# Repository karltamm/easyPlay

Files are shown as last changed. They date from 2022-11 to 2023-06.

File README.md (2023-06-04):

# EasyPlay

The aim of this project was to create a gadget that facilitates watching recorded lectures that are in a form of HTML5 video.

As a result of this, a custom-built hardware was designed and manufactured that communicates with a browser extension (_currently only on Firefox_) to control playback of HTML5 video and to
manage video bookmarks using graphical user interface (GUI).

## Demo Clips

- [Adding Bookmark](https://www.youtube.com/watch?v=zyzYwxNeeDU&list=PLD5j9DIB91if8dvnZOE8TOlPMy7ZPZOXh&index=4)
- [Bookmark List](https://www.youtube.com/watch?v=o9xNbJMG1ok&list=PLD5j9DIB91if8dvnZOE8TOlPMy7ZPZOXh&index=4)
- [Playing Bookmark](https://www.youtube.com/watch?v=D4asH7l5GT0&list=PLD5j9DIB91if8dvnZOE8TOlPMy7ZPZOXh&index=5)
- [Deleting Bookmark](https://www.youtube.com/watch?v=MK7uui3cbB4&list=PLD5j9DIB91if8dvnZOE8TOlPMy7ZPZOXh&index=6)
- [Choosing Playback Speed](https://www.youtube.com/watch?v=vUmaLGZ5vVY&list=PLD5j9DIB91if8dvnZOE8TOlPMy7ZPZOXh&index=1)
- [Rewinding & Fast-Forwarding](https://www.youtube.com/watch?v=-IeWby0tvKw&list=PLD5j9DIB91if8dvnZOE8TOlPMy7ZPZOXh&index=2)

## Hardware

- STM32F042C6T6 microcontroller (ARM Cortex-M0)
- Illuminated mechanical switches (Cherry MX) and knob (incremental rotary encoder)
- USB Type-C connector for communication and power delivery
- Custom designed [printed circuit board](https://raw.githubusercontent.com/karltamm/EasyPlay/main/hardware/Outputs/PCB%203D%20Print/PCB%203D%20model%20top.png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) (PCB) and enclosure ([exploded rendering](https://github.com/karltamm/EasyPlay/blob/main/enclosure/images/device-exploded-view.png) & [finished](https://github.com/karltamm/EasyPlay/blob/main/enclosure/images/assembled-device.png))

## Device Firmware

- Written in C
- Software based debounce for buttons and knob
- Simple task manager

## Device Driver

- Written in Java
- Uses [jSerialComm](https://fazecast.github.io/jSerialComm/) to communicate with the firmware
- Communicates with the browser extension using [native messaging protocol](https://developer.mozilla.org/en-US/docs/Mozilla/Add-ons/WebExtensions/Native_messaging)

## Browser extension

- Written in TypeScript
- Controls HTML5 video playback
- Allows to use video bookmarks using GUI (built with React)

## Driver Installer

- Written in C++
- Uses [Qt framework](https://www.qt.io/product/framework)
- Copies driver to chosen location
- Sets up [app manifest](https://developer.mozilla.org/en-US/docs/Mozilla/Add-ons/WebExtensions/Native_messaging#app_manifest) to use browser native messaging for communication between the driver and browser extension

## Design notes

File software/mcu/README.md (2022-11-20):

# Abbreviations used in source code

- btn - button
- CCW - counterclockwise
- comm - communication
- conn - connection
- cur - current
- CW - clockwise
- g\_ - global (variable naming)
- init - initialize
- len - length
- ms - millisecond
- msg - message
- PC - personal computer
- RX - receive
- TX - transmit
- UI - user interface
- sw - switch

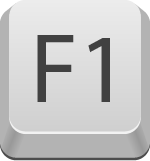
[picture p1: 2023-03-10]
software/extension/src/assets/images/150w/keycap-f1.png

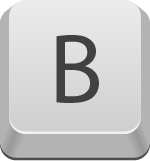
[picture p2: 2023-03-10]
software/extension/src/assets/images/150w/keycap-b.png

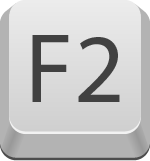
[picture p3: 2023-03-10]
software/extension/src/assets/images/150w/keycap-f2.png

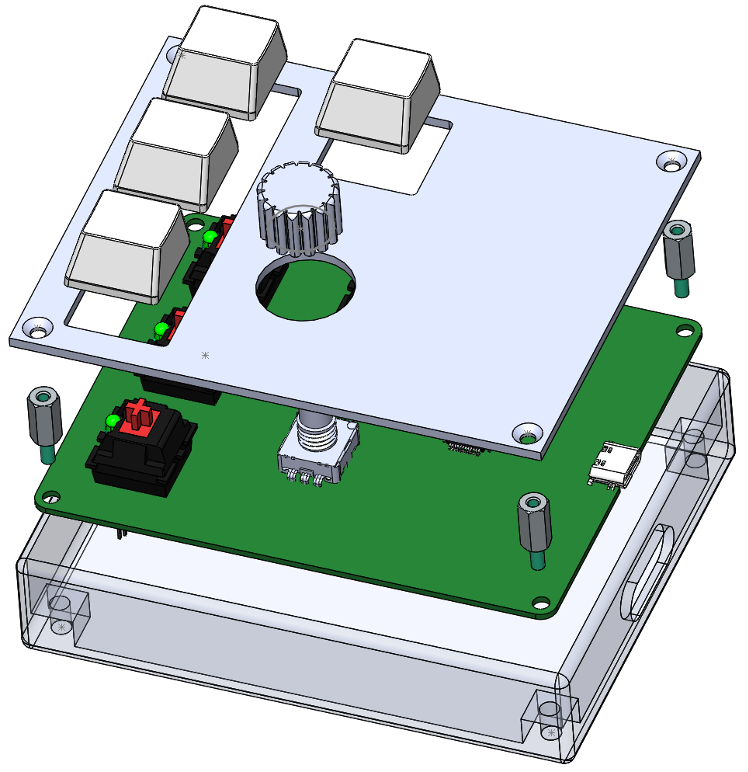
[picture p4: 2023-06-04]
enclosure/images/device-exploded-view.png

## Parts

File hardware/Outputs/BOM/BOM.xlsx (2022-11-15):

Library Reference | Manufacturer | Manufacturer ID | Supplier | Supplier ID | Quantity | Comment | Designator
5x1 Pin Header | AMPHENOL | 68000-105HLF | Farnell | 2751380 | 1 | ST-LINK | CON1-MCU
Capacitor | MULTICOMP PRO | MC0603B104J500CT | Farnell | 2320803 | 13 | 0.1uF, 50V, 0603 | C1-CTRL, C1-MCU, C2-CTRL, C2-MCU, C2-PWR, C3-CTRL, C3-MCU, C4-MCU, C4-PWR, C5-MCU, C6-CTRL, C7-CTRL, C7-MCU
Capacitor | MULTICOMP PRO | MC0603N200J500CT | Farnell | 2627461 | 2 | 20pF, 50V, 0603 | C6-MCU, C8-MCU
Capacitor | MURATA | GRM21BR6YA106KE43L | Farnell | 2611943 | 2 | 10uF, 35V, 0805 | C1-PWR, C3-PWR
Capacitor | YAGEO | CC0603KRX7R8BB103 | Farnell | 3019561 | 2 | 10nF, 25V, 0603 | C4-CTRL, C5-CTRL
Cherry MX Switch | Cherry Americas LLC | MX1A-11NW | Digi-Key | CH160-ND | 4 | Cherry MX, 10mA, 12V | SW1-CTRL, SW2-CTRL, SW3-CTRL, SW5-CTRL
Crystal 4-pin | MULTICOMP PRO | MCSJK-7U-25.00-12-10-60-B-10 | Farnell | 2853968 | 1 | 25MHz, 12pF, 3.2x2.5mm | Y1-MCU
ESD Protection Device | NEXPERIA | IP4234CZ6,125 | Farnell | 1829276 | 1 | 100W, SOT457 | U1-USB
LDO Regulator | Microchip | MCP1700T-3302E/TT | Farnell | 1296592 | 1 | 3.3V, 250mA | U1-PWR
LED | BROADCOM | HLMP-1401 | Farnell | 1003198 | 1 | 2Vf, 10mA, yellow, TH, no footprint | D2-CTRL
LED | KINGBRIGHT | KP-1608CGCK | Farnell | 2290328 | 1 | 2.1Vf, 20mA, green, 0603 | D2-MCU
LED | KINGBRIGHT | KP-1608SYC | Farnell | 8529841 | 1 | 2Vf, 20mA, yellow, 0603 | D1-MCU
LED | MULTICOMP PRO | MP008246 | Farnell | 3796272 | 3 | 1.8Vf, 2mA, green, TH, no footprint | D1-CTRL, D3-CTRL, D4-CTRL
LED | VISHAY | VLMS1300-GS08 | Farnell | 2251484 | 1 | 2Vf, 20mA, red, 0603 | D2-PWR
Molex USB 2.0 Type-C Receptacle | MOLEX | 216990-0003 | Farnell | 3702962 | 1 | UFP | CON1-USB
Resistor | BOURNS | CR0603-FX-1001ELF | Farnell | 2008335 | 9 | 1k, 100mW, 0603 | R3-CTRL, R4-CTRL, R5-CTRL, R6-CTRL, R9-CTRL, R11-CTRL, R15-CTRL, R17-CTRL, R18-CTRL
Resistor | MULTICOMP PRO | MC0805S8F0000T5E | Farnell | 2309112 | 4 | 0R, 125mW, 0805 | R1-USB, R2-USB, R3-USB, R4-USB
Resistor | YAGEO | RC0603FR-075K1L | Farnell | 3495881 | 2 | 5.1k, 100mW, 0603 | R5-USB, R6-USB
Resistor | YAGEO | RC0603FR-0710KL | Farnell | 9238603 | 4 | 10k, 100mW, 0603 | R8-CTRL, R10-CTRL, R12-CTRL, R13-CTRL
Resistor | YAGEO | RC0603FR-07270RL | Farnell | 9238417 | 3 | 270R, 100mW, 0603 | R1-MCU, R1-PWR, R2-MCU
Resistor | YAGEO | RC0603FR-13100KL | Farnell | 2309107 | 5 | 100k, 100mW, 0603 | R1-CTRL, R2-CTRL, R7-CTRL, R14-CTRL, R16-CTRL
Rotary Encoder w/ Switch | Bourns | PEC11H-4015F-S0016 | Digi-Key | 118-PEC11H-4015F-S0016-ND | 1 | Rotary Encoder w/ Switch | SW4-CTRL
Schottky Rectifier (Diode) | NEXPERIA | PMEG3030EP,115 | Farnell | 1829195 | 1 | 30Vbr, 3A, 360mVf | D1-PWR
STM32F042C6T6 (MCU) | STMicroelectronics | STM32F042C6T6 | JLCPCB | C88447 | 1 | STM32F042C6T6 | U1-MCU

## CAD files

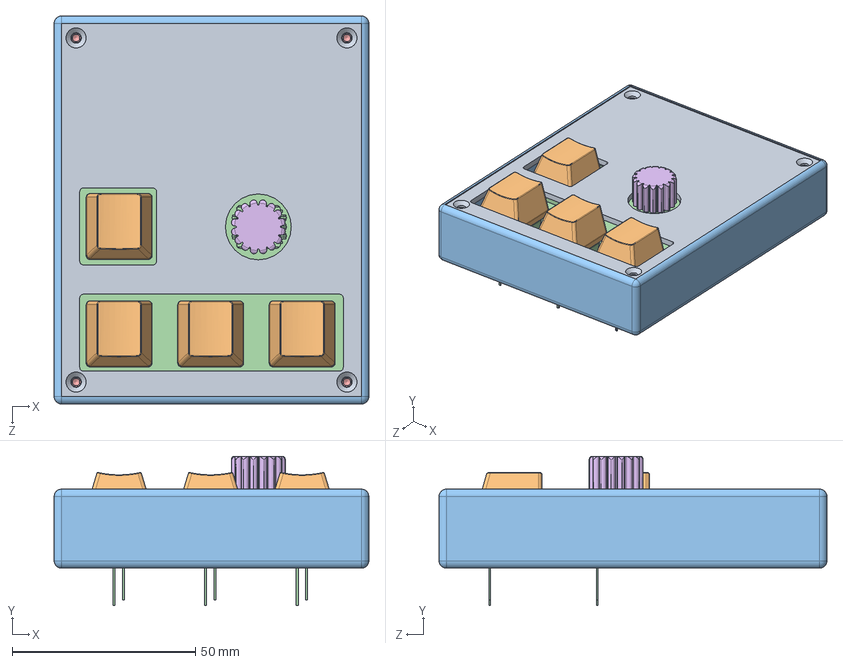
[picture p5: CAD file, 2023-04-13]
enclosure/DeviceAssembly.SLDASM
86.0 x 40.8 x 106.0 mm
PCB
Standoff x 4
Keycap x 4
Knob cap
Lid

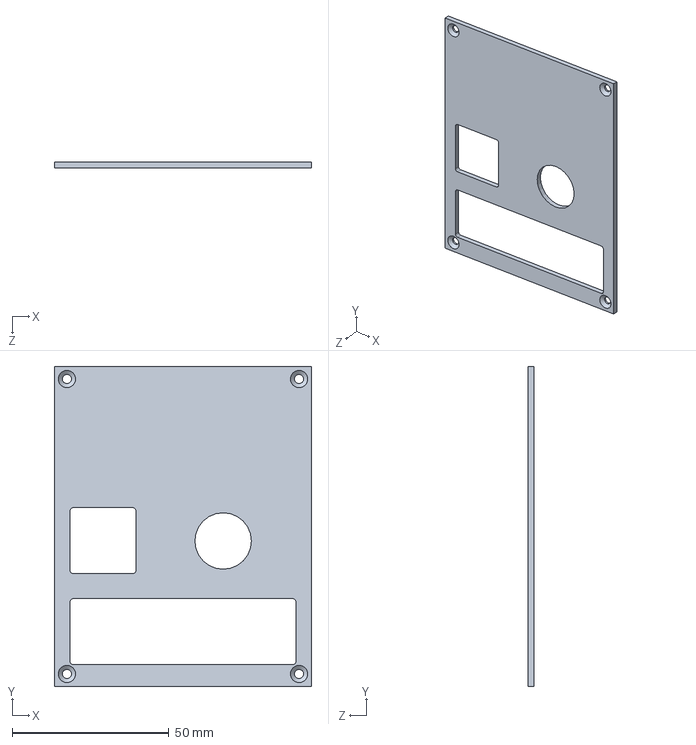
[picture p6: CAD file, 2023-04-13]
enclosure/Lid.SLDPRT
82.0 x 102.0 x 2.00 mm

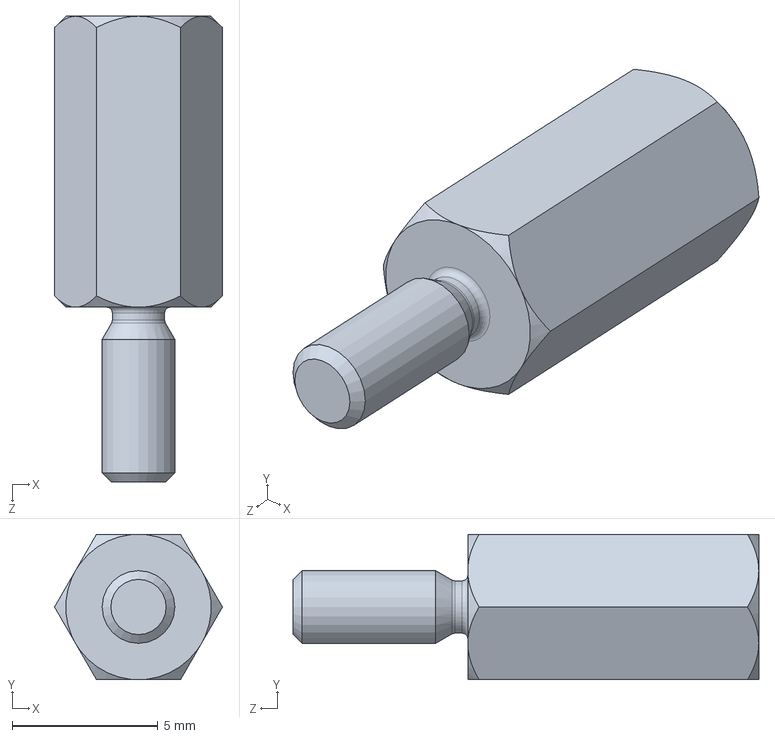
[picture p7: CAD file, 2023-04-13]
enclosure/products/Standoff.SLDPRT
5.77 x 5.00 x 16.0 mm

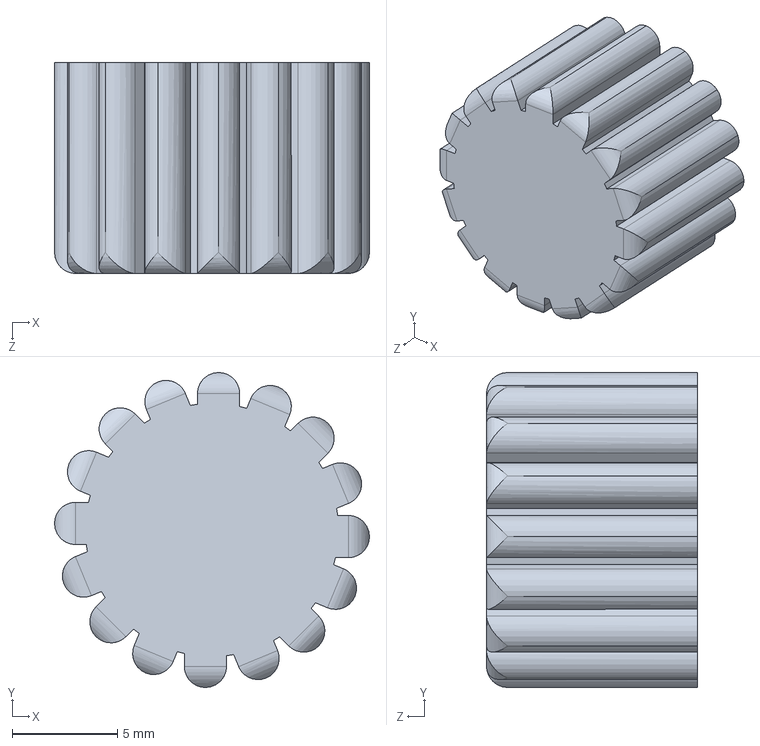
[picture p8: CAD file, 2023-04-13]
enclosure/Knob cap.SLDPRT
14.9 x 14.9 x 10.0 mm

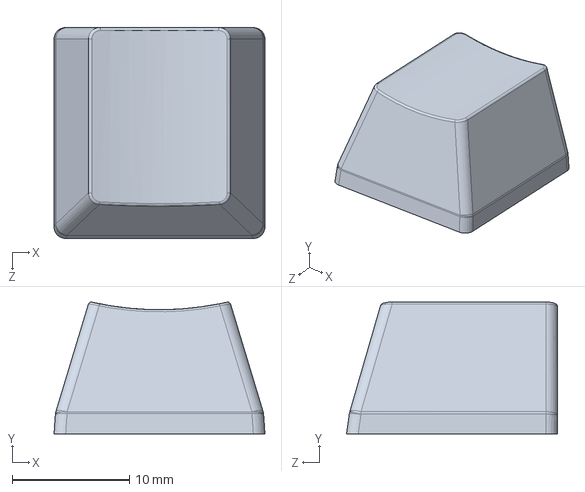
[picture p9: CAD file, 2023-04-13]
enclosure/products/Keycap.SLDPRT
18.0 x 11.3 x 18.0 mm

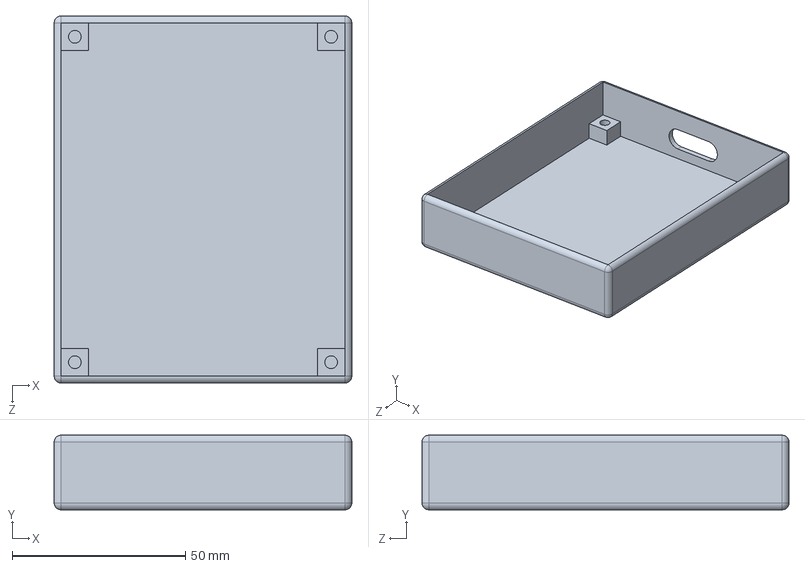
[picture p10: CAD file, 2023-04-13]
enclosure/Box.SLDPRT
86.0 x 21.6 x 106.0 mm

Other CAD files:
enclosure/stl/Box.STL
enclosure/stl/Knob cap.STL
enclosure/stl/Lid.STL

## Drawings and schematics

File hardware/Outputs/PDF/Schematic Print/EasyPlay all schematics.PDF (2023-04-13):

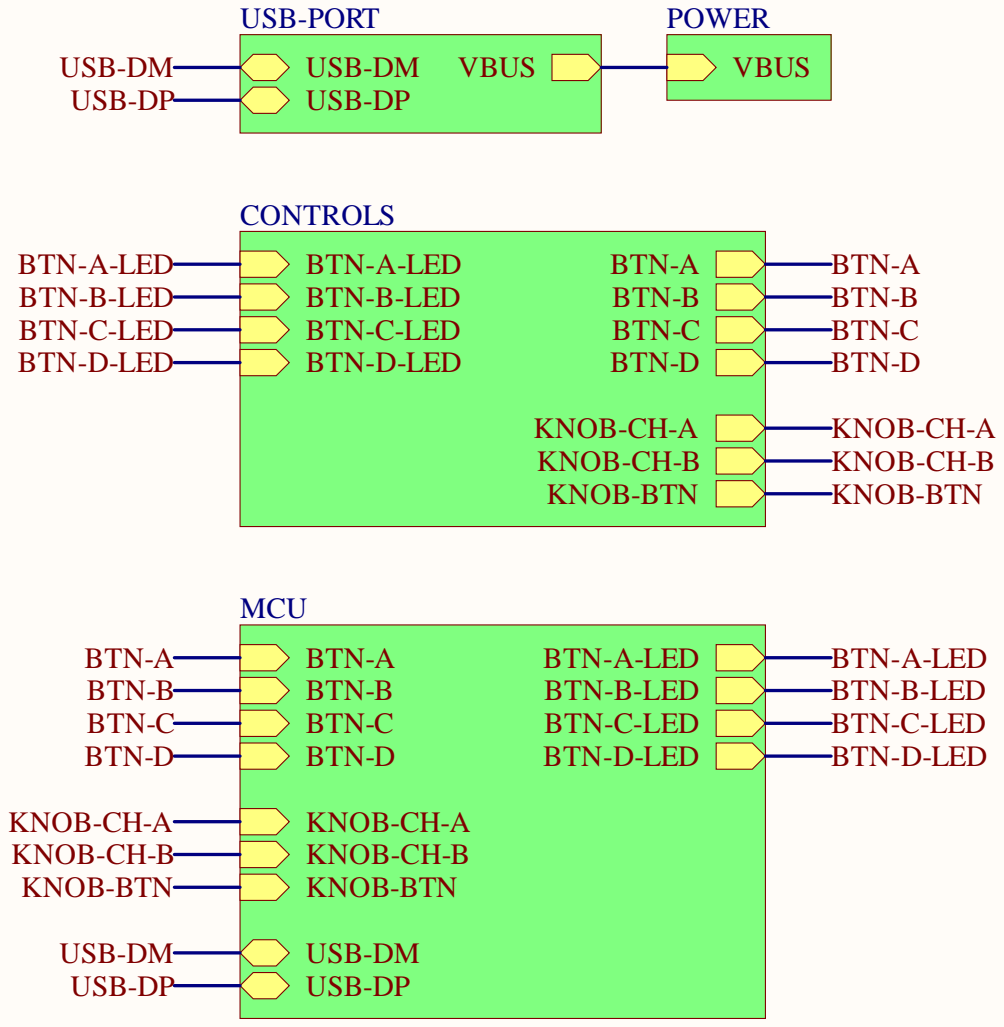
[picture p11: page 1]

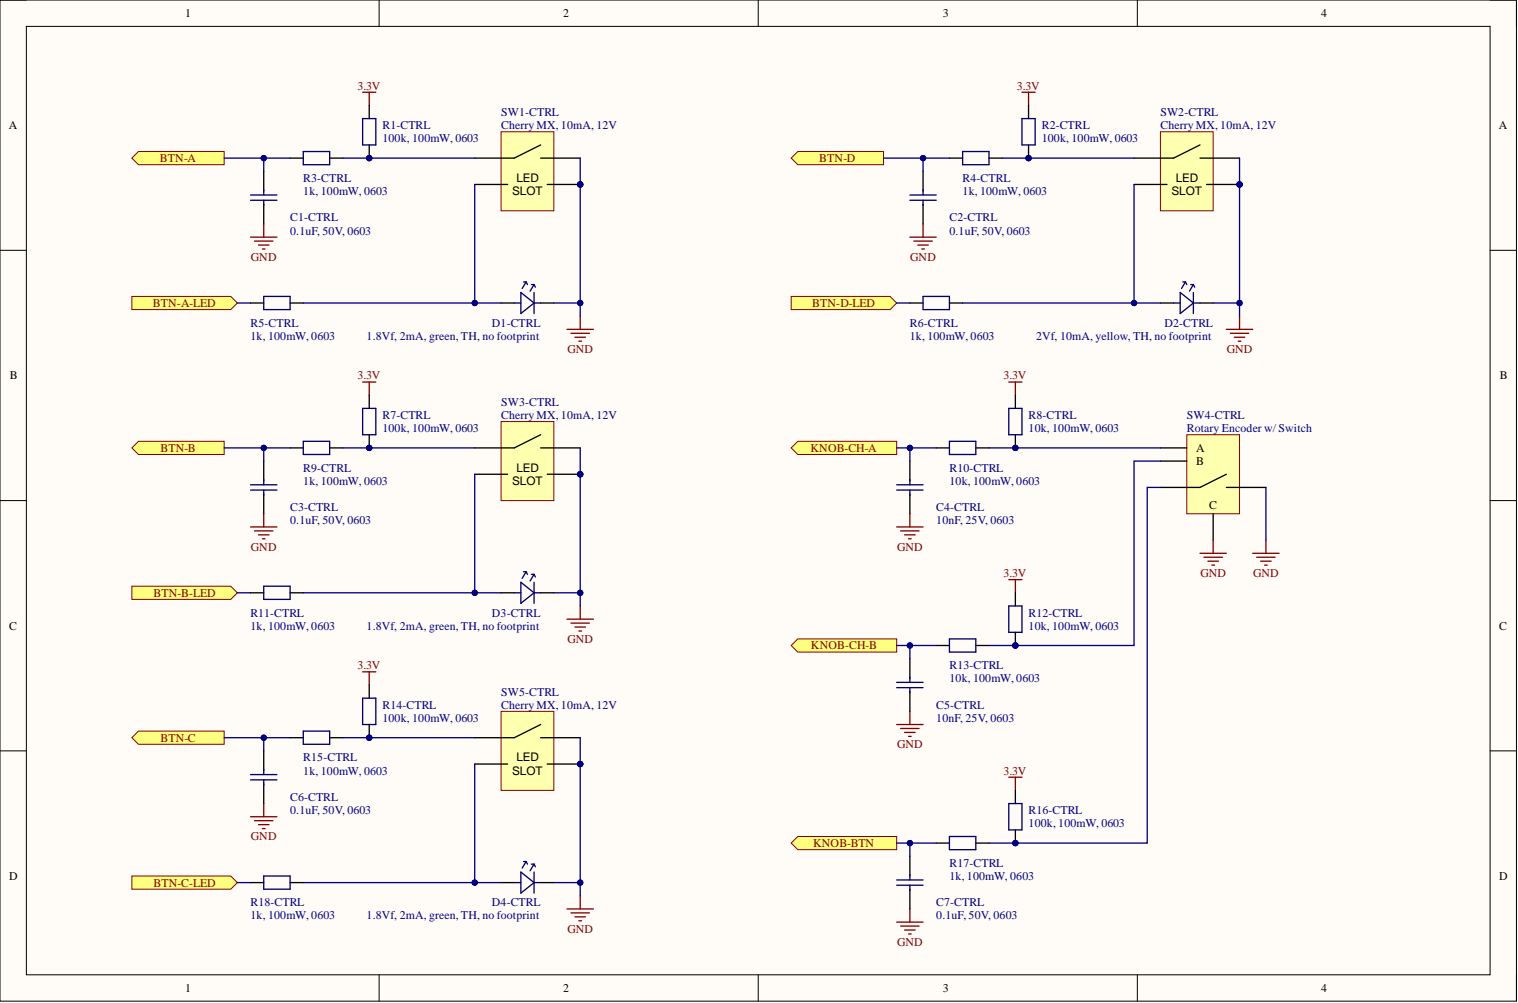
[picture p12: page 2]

1.8Vf, 2mA, green, TH, no footprint

2Vf, 10mA, yellow, TH, no footprint

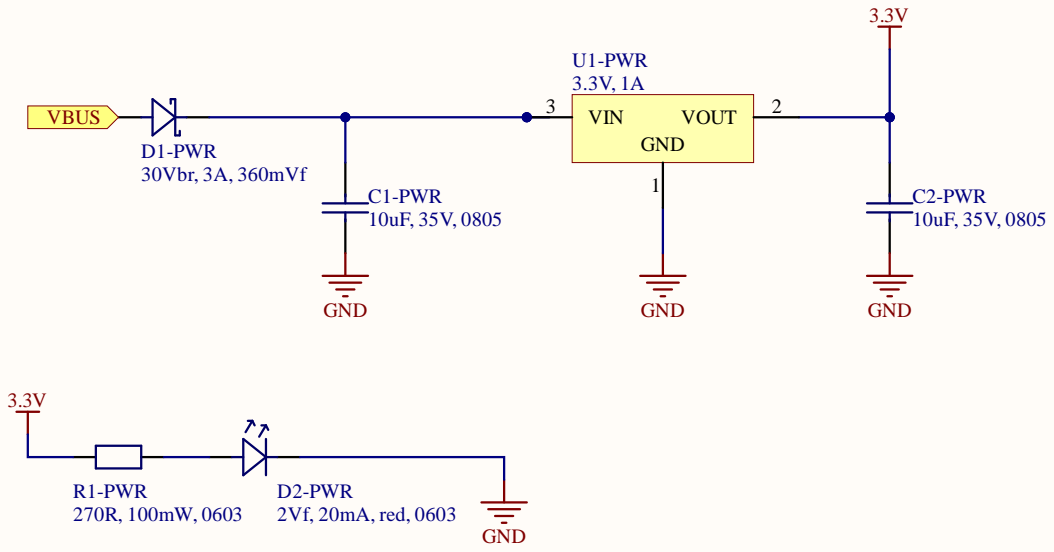
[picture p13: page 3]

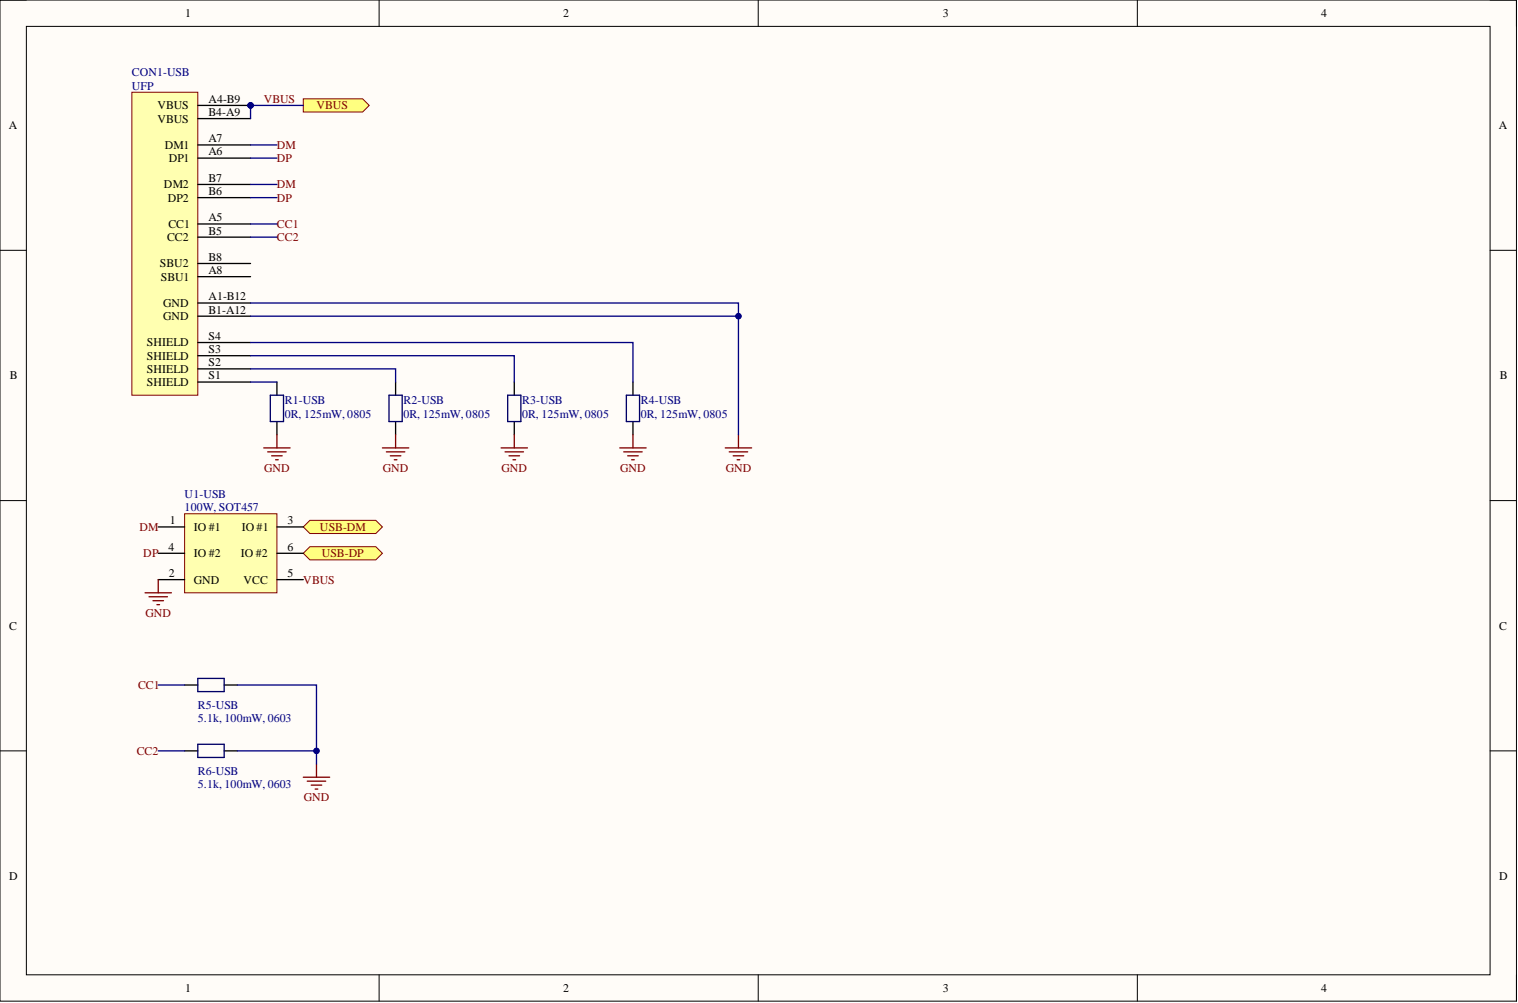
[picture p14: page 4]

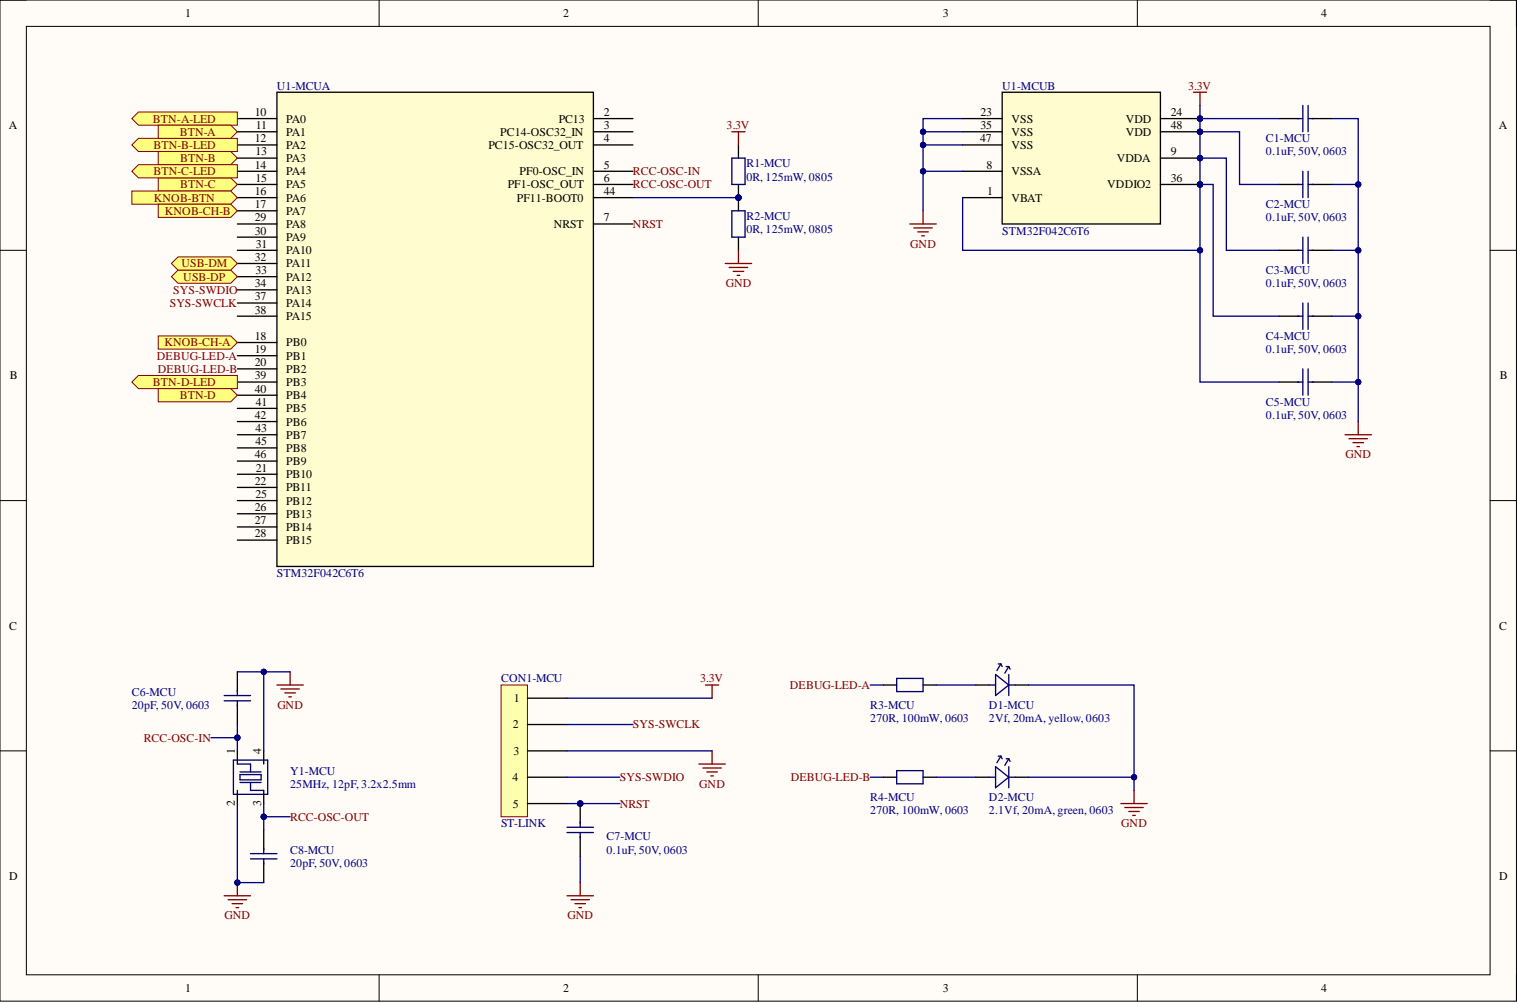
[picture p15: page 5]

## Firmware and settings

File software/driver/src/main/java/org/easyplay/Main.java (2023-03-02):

package org.easyplay;

import lombok.extern.slf4j.Slf4j;

import static org.easyplay.UsbCommunicator.USB_RX_QUEUE_MAX_SIZE;
import static org.easyplay.UsbCommunicator.USB_TX_QUEUE_MAX_SIZE;


@Slf4j
public class Main {
    public static void main(String[] args) {
        log.info("Booting up app");
        UsbQueue usbTxQueue = new UsbQueue(USB_TX_QUEUE_MAX_SIZE, "usbTxQueue");
        UsbQueue usbRxQueue = new UsbQueue(USB_RX_QUEUE_MAX_SIZE, "usbRxQueue");
        new UsbCommunicator(usbTxQueue, usbRxQueue).start();
        new BrowserCommunicator(usbTxQueue, usbRxQueue).start();
        log.info("Booting up completed");
    }
}

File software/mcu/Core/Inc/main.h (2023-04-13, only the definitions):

#define BTN_A_LED_Pin GPIO_PIN_0
#define BTN_A_LED_GPIO_Port GPIOA
#define BTN_A_Pin GPIO_PIN_1
#define BTN_A_GPIO_Port GPIOA
#define BTN_B_LED_Pin GPIO_PIN_2
#define BTN_B_LED_GPIO_Port GPIOA
#define BTN_B_Pin GPIO_PIN_3
#define BTN_B_GPIO_Port GPIOA
#define BTN_C_LED_Pin GPIO_PIN_4
#define BTN_C_LED_GPIO_Port GPIOA
#define BTN_C_Pin GPIO_PIN_5
#define BTN_C_GPIO_Port GPIOA
#define KNOB_BTN_Pin GPIO_PIN_6
#define KNOB_BTN_GPIO_Port GPIOA
#define KNOB_CH_B_Pin GPIO_PIN_7
#define KNOB_CH_B_GPIO_Port GPIOA
#define KNOB_CH_A_Pin GPIO_PIN_0
#define KNOB_CH_A_GPIO_Port GPIOB
#define DEBUG_LED_B_Pin GPIO_PIN_1
#define DEBUG_LED_B_GPIO_Port GPIOB
#define DEBUG_LED_A_Pin GPIO_PIN_2
#define DEBUG_LED_A_GPIO_Port GPIOB
#define BTN_D_LED_Pin GPIO_PIN_3
#define BTN_D_LED_GPIO_Port GPIOB
#define BTN_D_Pin GPIO_PIN_4
#define BTN_D_GPIO_Port GPIOB

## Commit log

2022-10-26 PCB 1.0
    [BOM.xlsx, CONTROL-SWITCHES.SchDoc, EasyPlay.PrjPcb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]
2022-11-12 MCU software (#1)
    [CONTROL-SWITCHES.SchDoc, CONTROLS.SchDoc, EasyPlay.PrjPcb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]
2022-11-15 PCB passive component values (#2)
    [BOM.xlsx, CONTROLS.SchDoc, PCB.PcbDoc]
2022-11-20 MCU software updates (#3)
    Changes:
    - USB bug fixes
    - Software debounce for switches
    - Release version configuration
    - Delay at boot to stabilize the switches RC filter
    [EasyPlay.ioc, buttons.c, knob.c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]
2022-11-23 MCU software updates (#4)
    * USB TX message doesn't end with null character
    * Added USB "no connection" indicator
    * Not saving user input if USB not connected
    * Increased debounce period for buttons and knob
    * Added license
    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
    [buttons.c]
2023-03-02 Device driver (#5)
2023-03-10 Basic extension (#6)
    - User can play/pause and rewind/fast-forward video
    - User can select playback speed
    - User can add, play and delete bookmarks
    - User can see feedback as notifications
    - Currently only YouTube is supported
    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
2023-03-19 Added Coursera (#7)
    - New regex checker
    - Send messages from device to every active tab
    - Using interval to find video HTML element
    - Using top-level async functionality
    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
2023-03-30 Installer (#10)
    - Qt based installer
    - Checks if Firefox and JRE are installed
    - Option to uninstall previous installations
    - Writes native app manifest path to Mozilla registry
    - Copies driver and manifest to chosen directory
    - Extension gets no warnings from linter
    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
2023-03-30 Extension 1.0.5 (#12)
    * Loading content scripts using manifest
    * Fixed buttons font size
    * Resetting video speed on page load and tab URL change
    * Accessing data only on Youtube and Coursera
    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
2023-04-13 Enclosure (#11)
    [Box.SLDPRT, Box.STL, DeviceAssembly.SLDASM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]
2023-04-13 PCB 1.1 (#8)
    * Updated LDO voltage regulator and using proper pins for button D
    * Switches and rotary encoder components are on the bottom side of PCB
    * MCU uses HSI clock
    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
    [EasyPlay.PrjPcb, MCU.SchDoc, PCB.PcbDoc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]
2023-04-14 Update LEDs on tab activation (#14)
2023-04-19 Driver logging fix (#16)
    Driver logger doesn't log any status info to STDOUT anymore because the driver uses STDOUT to communicate with the extension (browser native messaging)
2023-04-26 Driver logging improvement (#18)
2023-04-30 Driver Logback improvements (#20)
2023-06-04 Updated README and added enclosure images (#21)
    [Box.SLDPRT, Box.STL, DeviceAssembly.SLDASM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]
2023-06-04 Updated photo of device

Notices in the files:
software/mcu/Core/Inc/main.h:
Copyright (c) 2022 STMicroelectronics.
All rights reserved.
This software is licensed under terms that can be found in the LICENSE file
